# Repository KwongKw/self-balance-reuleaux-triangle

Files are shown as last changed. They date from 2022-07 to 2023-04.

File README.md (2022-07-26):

# FYP_ESP32_Self-BalanceReuleauxTriangle
It is an FYP based on the design of the self-balance Reuleaux triangle. 

To maintain the unsatble equilibrium state. the force provided by the momentum wheel need to be calculated based on the physical state of the triangle.



## Procedures

### PCB design

#### Apperance
  
- To ease the rotation of the system, the reuleaux triangle is used in the design, to minimize the force required for the system.

#### MCU

Arduino/ESP series MCUs are preferred. 
- Arduino has a well-developed library for implementing this project. 
ESP series provide wireless features including wireless programming, control, and system monitoring, and a relatively high compatibility with arduino library.

#### Sensors
- To monitor the state (angle of rotation) of the system, accelerometers are considered to be used to detect the tilt angle.

####	Motor
- To provide enough rotational force for the system, the momentum wheel is considered to be used to provide the required force

#### Charging Circuit (Optional)
- To prevent wires from affecting the mobility of the system. Power supply is better to be embedded into the system.

###	Control System
To enhance the performance for the system, different control systems will be tested on maintaining the unstable equilibrium system.

###	Calibratio
To tune the system, collect and interpret data extracted from the system, and make improvements on the system.

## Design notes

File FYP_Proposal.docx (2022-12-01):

The Hong Kong Polytechnic University

Department of Electronic and Information Engineering

Final Year Project Proposal

Self-Balance Reuleaux Triangle

Wong Keith

19067393d

Ka-Hong Loo

14-10-2022

Abstract

This project examines the self-balance Reuleaux triangle project, which can jump and balance itself on a corner (Fig. 1) [1].

A reaction wheel is embedded between two PCBs designed in the shape of a Reuleaux triangle; the reaction wheel provides a sudden force for the system to jump by braking a high-speed rotating momentum wheel suddenly; when the system reaches its unstable equilibrium state (standing with its corner), the reaction wheel is controlled to provide adjustment force for the system to prevent the system from falling.

The project aims to reproduce the design and research the performance of different control systems acting on the model.

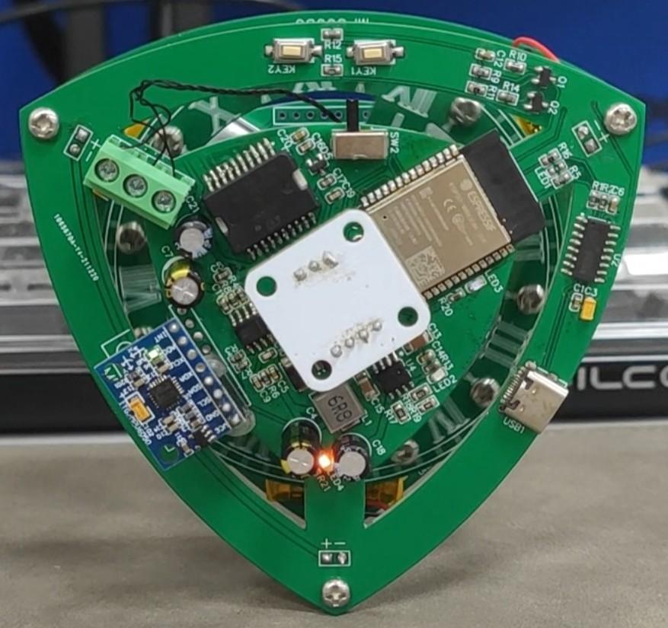
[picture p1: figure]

(Fig. 1)
Video: ﷟HYPERLINK "https://www.reddit.com/r/ElectroBOOM/comments/styhj0/selfbalanced_reuleaux_triangle/"https://www.reddit.com/r/ElectroBOOM/comments/styhj0/selfbalanced_reuleaux_triangle/ [1]

Introduction

Inverted pendulum plants are nonlinear systems widely used for testing different control algorithms [2]. The algorithm can be implemented in various fields which require stability, including vehicles (E.g., Rocket, Drone, Hoverboard, Segway), robotics (Postural controls, like walking, single leg stand) development, and even seismic control of building structures.

Reaction wheels are commonly used in the space industry; they are flywheels that can store rotational energy by rotation and trigger momentum exchange to supply rotational force for the vehicle [3][4]. Due to the high pointing accuracy provided by the wheels, the space vehicles can perform precise angle adjustments to implement exact tasks like satellite orientations and pointing the telescope at a star. Although using reaction wheels effectively reduces the need for thrusters and fuel to load onboard, the wheel can only perform rotational adjustments with respect to the center of mass.

The model concatenated both concepts mentioned above, and it is a prototype proving the use of reaction wheels on stabilizing inverted pendulum plants. There are similar projects which also demonstrate the idea, the Cubli [5], a three dimension balancing cube system on a corner.

The project will focus on implementing the product and investigating how the control systems differ in the product's

Objective

It is a project based on reproducing the product of the Self-Balance Reuleaux Triangle. The project aims to perform an unstable equilibrium with the aid of different control systems on the model.

Methodology

1. PCB Design

The contour of the PCB, which is also the main structure of the model, would be designed in the shape of the Reuleaux triangle to ease the rotation of the model. As the locus of the Reuleaux triangle is more smooth than that of ordinary triangles and squares, the sudden force needed for lifting the system can be smaller, easier the design of the reaction wheel.

The PCB design will then be sent to companies for manufacturing boards or passed to the Industrial Center for production.

  a. MCU

Computing unit for obtaining sensors' value, adjusting PWM for the motor, and the control system of the product. The following commonly used MCUs are considered.

Arduino series MCUs own a wide variety of well-developed libraries for implementing the project.

ESP series MCUs provide numerous wireless features to ease the project's development, including wireless programming, control, and system monitoring via Bluetooth and WiFi connection and relatively well-developed libraries.

STM series MCUs included a Low Layer (LL) library and hardware abstraction layer (HAL) that would have a higher degree of freedom in controlling the MCU and the hardware components. However, the ecosystem of STM lags behind the others, making the project complicated to implement.

  b. Sensors

Tilt angles need to be detected to perform the feedback control. The following are sensors to be considered.

Accelerometers are used to detect the tilt angle.

Ultrasonic sensors can also be used to help detect the distance from the corner to the ground, hence calculating the angle of rotation.

  c. Motor

To provide rotational force for the system. The motor with enough torque, which is required to be calculated after the PCB production, for driving the momentum wheel is needed.

  d. Charging Circuit (Optional)

To prevent wires from affecting the system's mobility. The power supply is better to be embedded into the system.

2. Control System

To enhance the system's performance. Different control systems (E.g., Proportional Integral Derivative (PID), Linear Quadratic Regulator (LQR) controller, and Model Predictive Control (MPC) [6]) will be tested to keep the unstable equilibrium system.

3. Calibration

To tune the system, collect and interpret data extracted from the system, and make improvements to the system.

Research Fields

1. PCB Designing

Designing a workable PCB and implementing it on a workable product.

2. MCU

System control and IOs via MCUs.

3. Control System

Research how different control systems (e.g., PID, LQR, MPC) act differently on this system, studying improvements and optimizations that can be performed on the system based on the data extracted.

Schedule

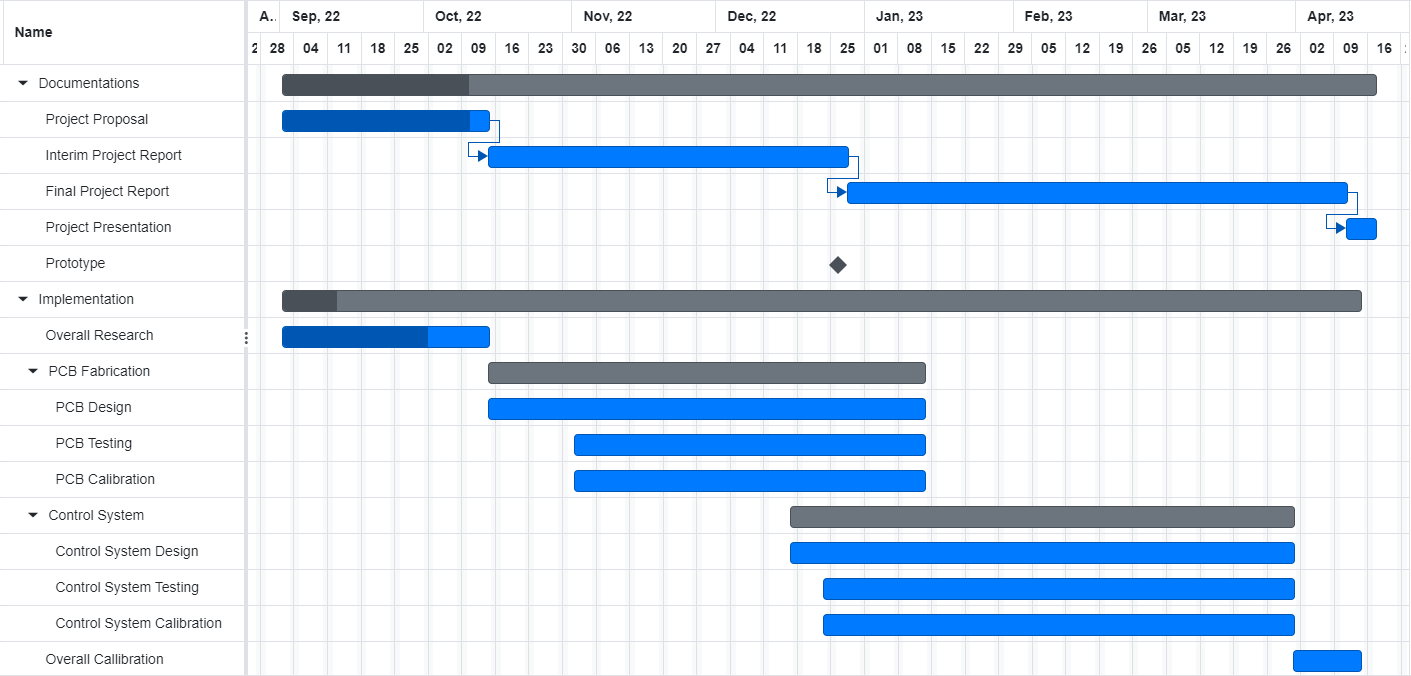
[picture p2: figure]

Reference

[1] "R/electroboom - self-balanced Reuleaux triangle!!!!!(),” Reddit. [Online]. Available: https://www.reddit.com/r/ElectroBOOM/comments/styhj0/selfbalanced_reuleaux_triangle/. [Accessed: 14-Oct-2022].

[2] E. Acurio, 'Mechanical redesign and control with a PLC of an inverted pendulum,' Congreso de Ciencia y Tecnología (ESPE), vol. 33, pp. 188, 2015.

[3] F. L. Markley, R. G. Reynolds, F. X. Liu, and K. L. Lebsock, "Maximum torque and momentum envelopes for reaction wheel arrays," Journal of Guidance, Control, and Dynamics, vol. 33, no. 5, pp. 1606–1614, 2010.

[4] M. Adetoro, COMPARATIVE DESIGN OF ATTITUDE STABILIZATION AND CONTROL SCHEMES FOR THREE AXES SPACE VEHICLE. Master Thesis on the direction "Instrumentation," 2010.

[5] M. Gajamohan, M. Merz, I. Thommen, and R. D'Andrea, "The Cubli: A cube that can jump up and balance," 2012 IEEE/RSJ International Conference on Intelligent Robots and Systems, 2012.

[6] S. Dani, D. Sonawane, D. Ingole, and S. Patil, "Performance evaluation of PID, LQR and MPC for DC Motor Speed Control," 2017 2nd International Conference for Convergence in Technology (I2CT), 2017.

Wong Keith 19067393D FYP Proposal

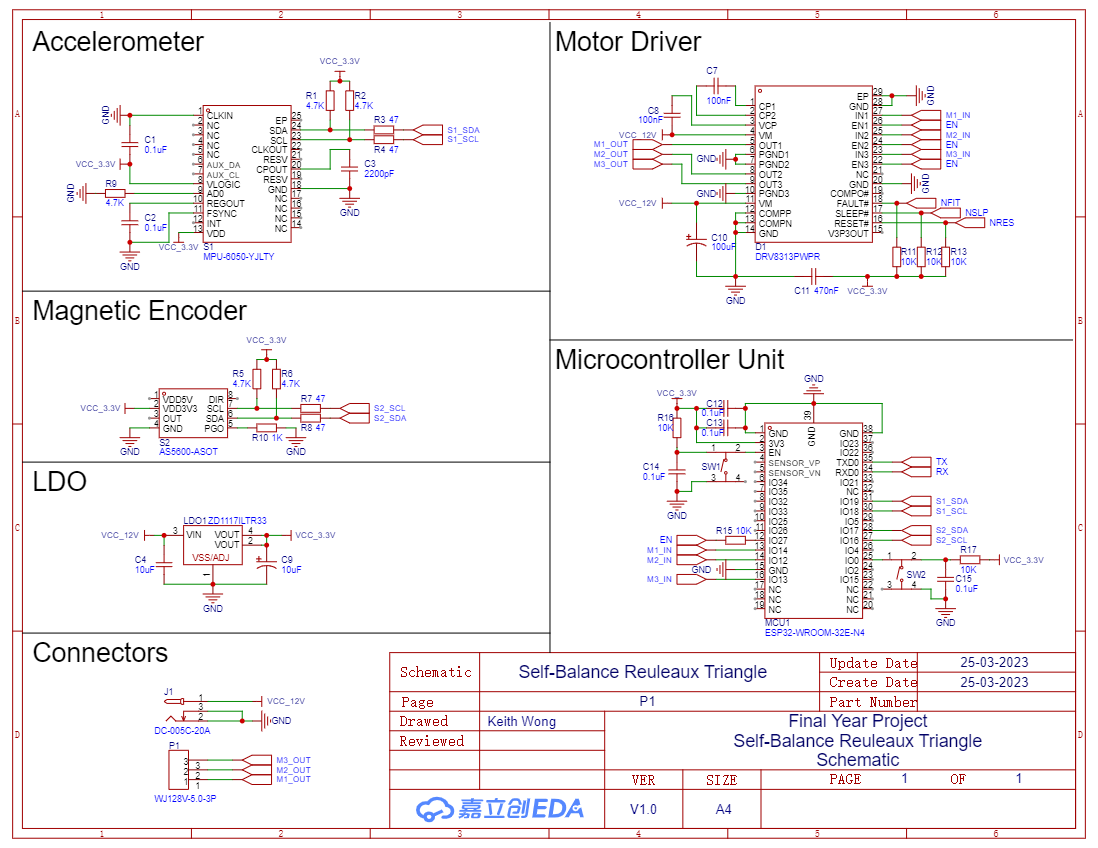
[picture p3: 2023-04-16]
hw/PCB/Schematic.png

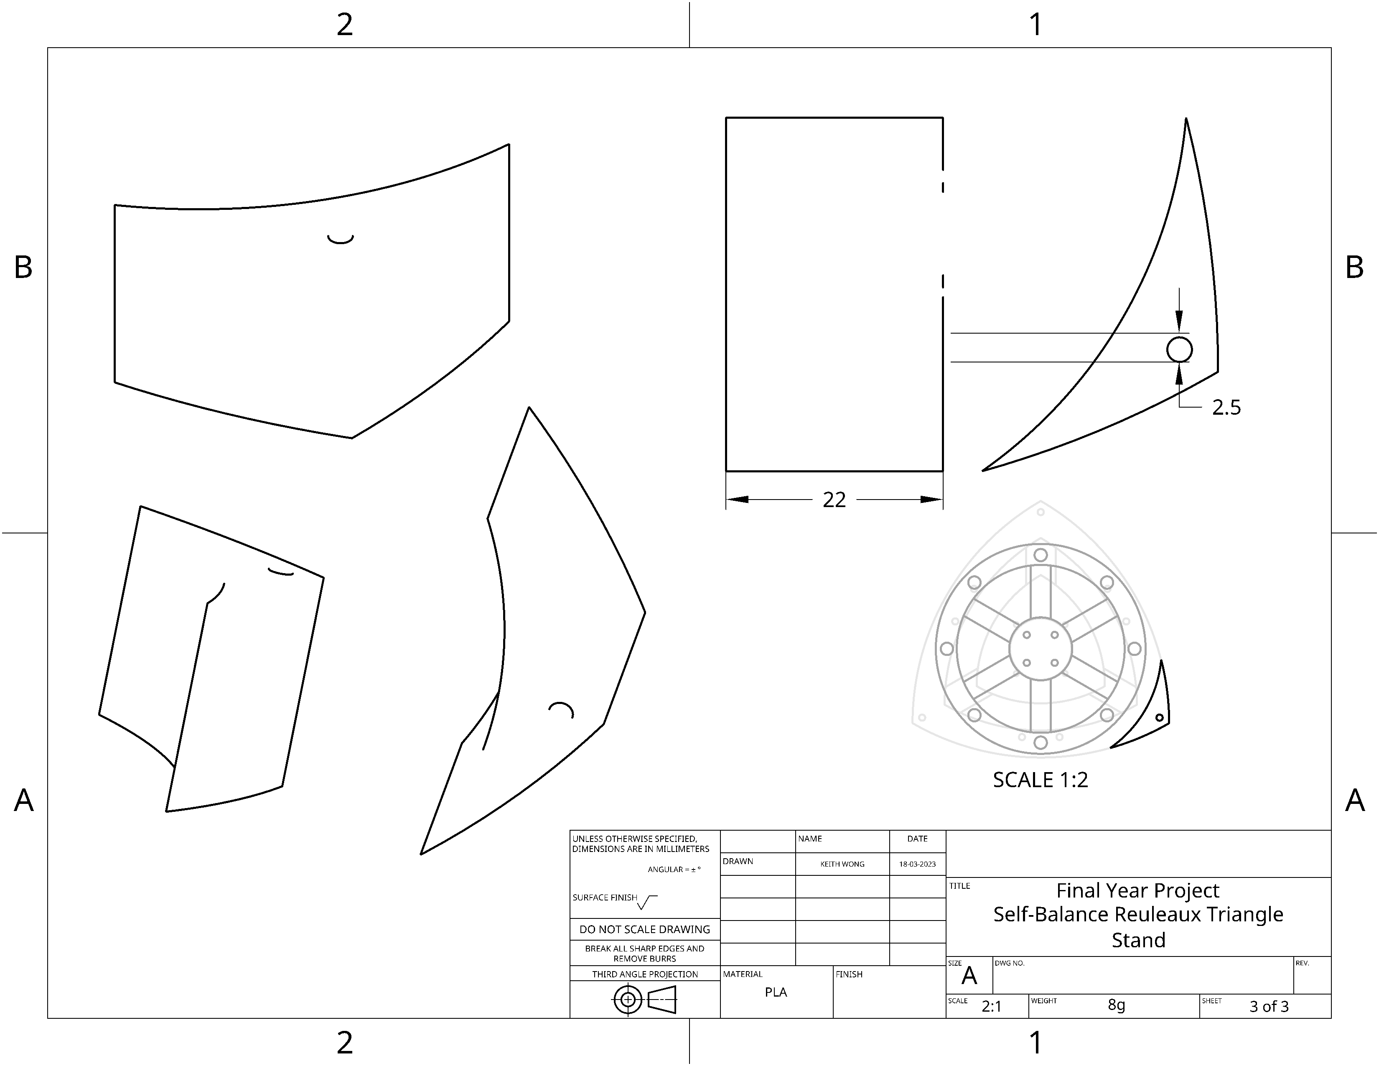
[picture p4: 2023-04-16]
hw/3D Model/Drawings/Stand.png

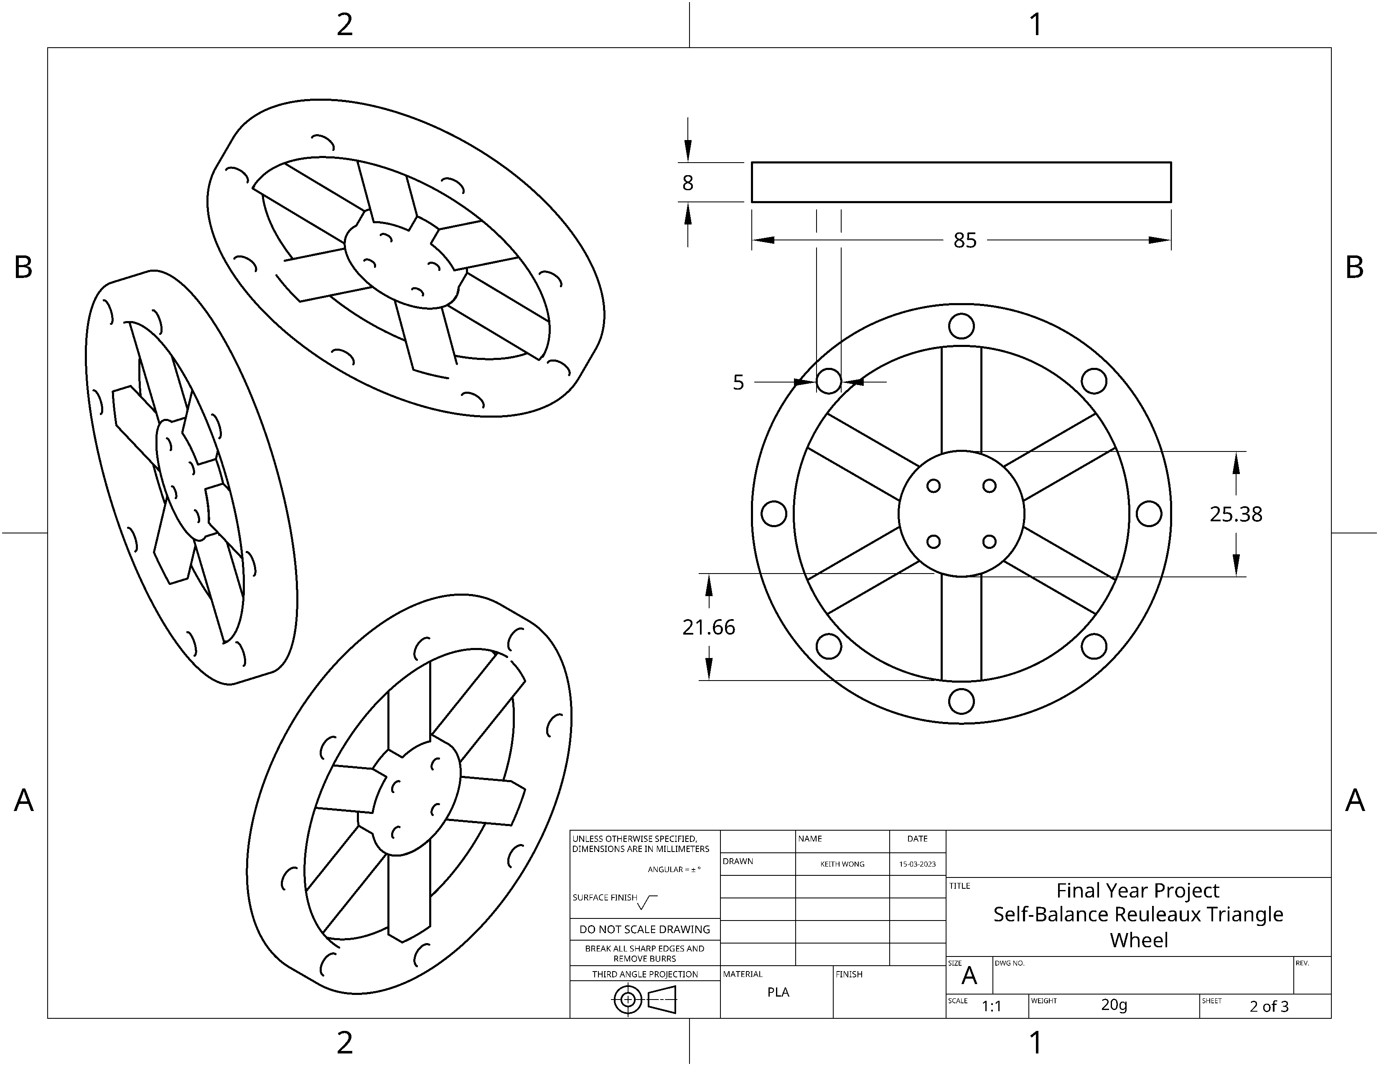
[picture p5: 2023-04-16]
hw/3D Model/Drawings/Wheel.png

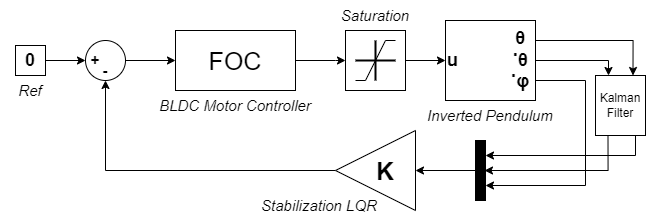
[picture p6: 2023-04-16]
hw/3D Model/Drawings/ControlSystem.png

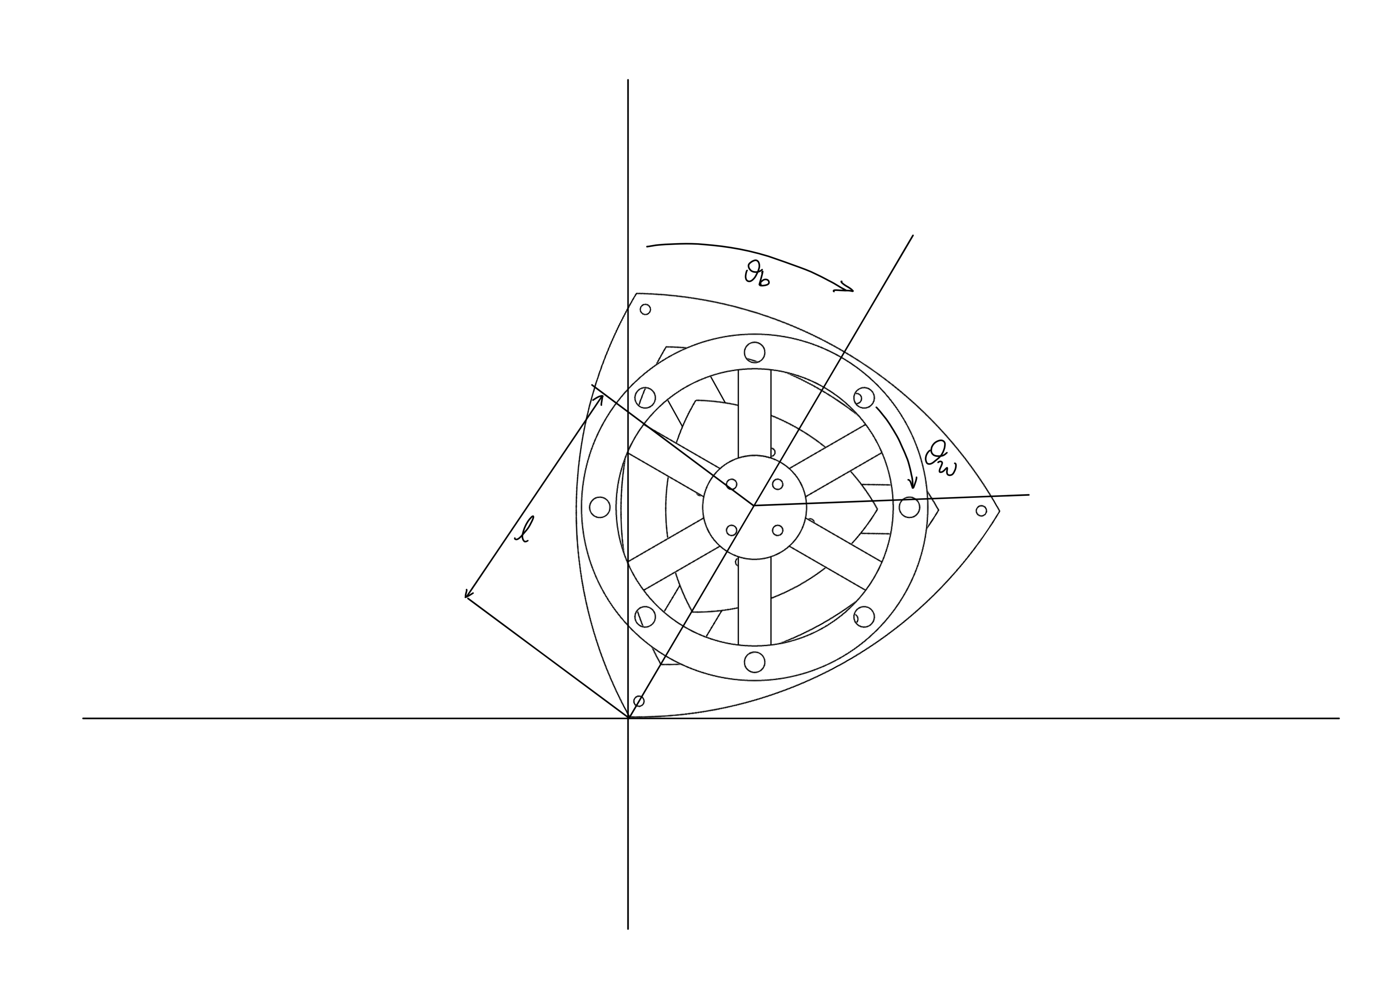
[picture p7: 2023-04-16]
hw/3D Model/Drawings/MathematicalModel.png

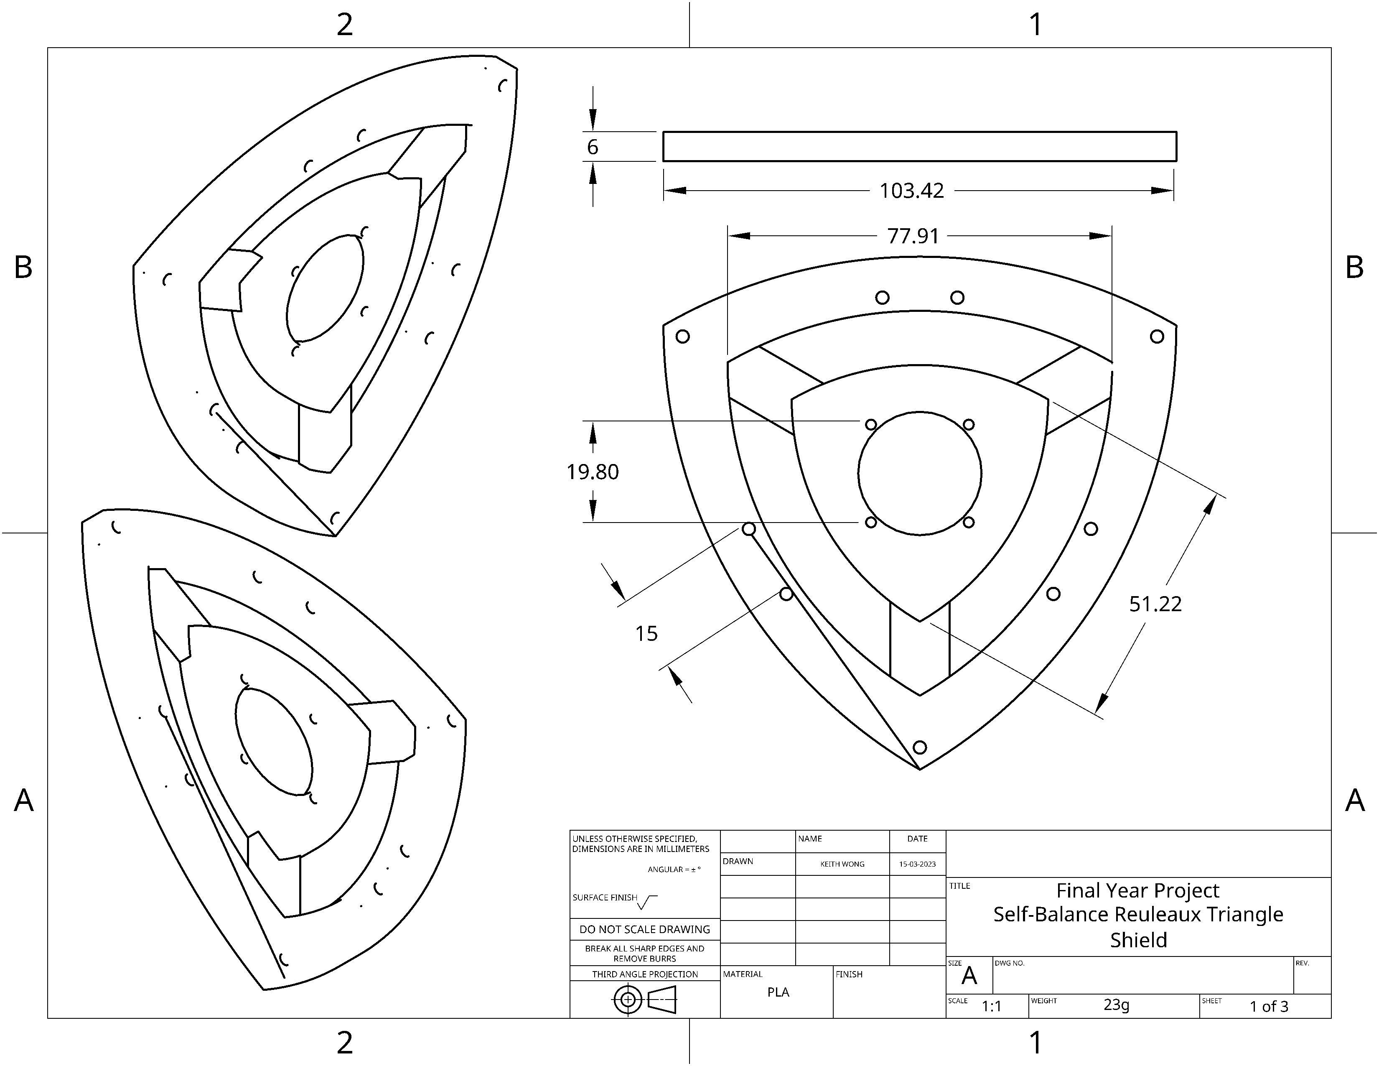
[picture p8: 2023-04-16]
hw/3D Model/Drawings/Shield.png

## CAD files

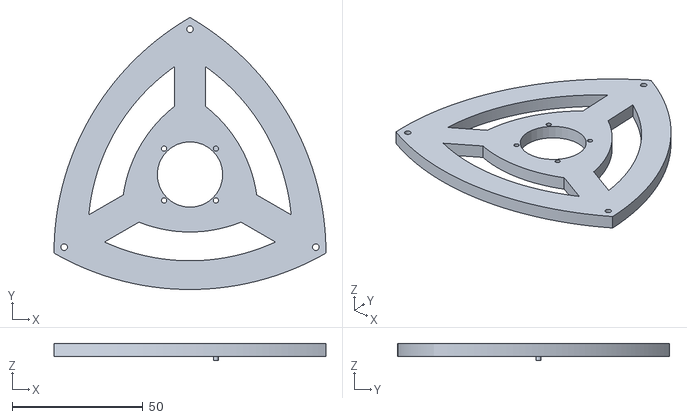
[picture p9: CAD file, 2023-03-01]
3D_Model/V2/Reuleaux.stl
103.9 x 103.9 x 6.50

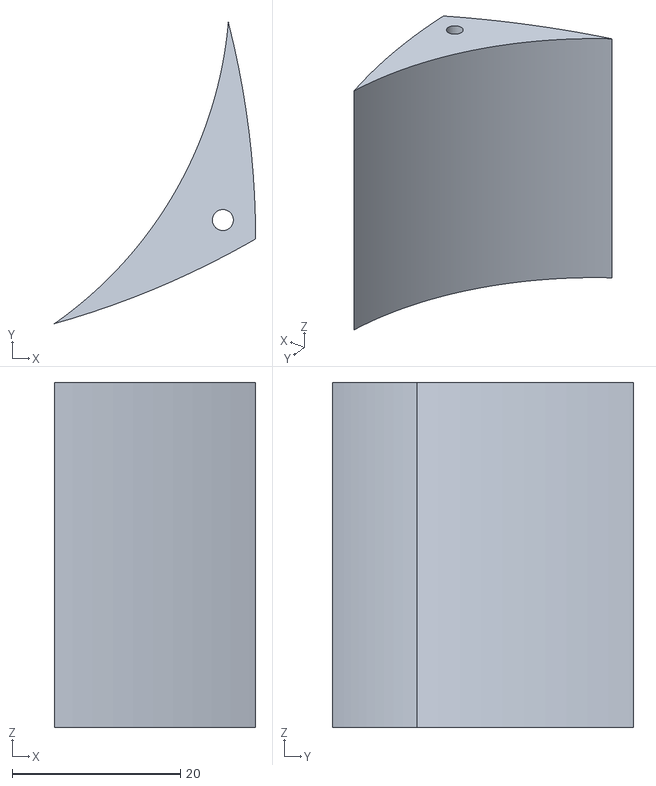
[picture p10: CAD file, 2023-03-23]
hw/3D Model/V3/Connectors.stl
23.9 x 35.8 x 41.0

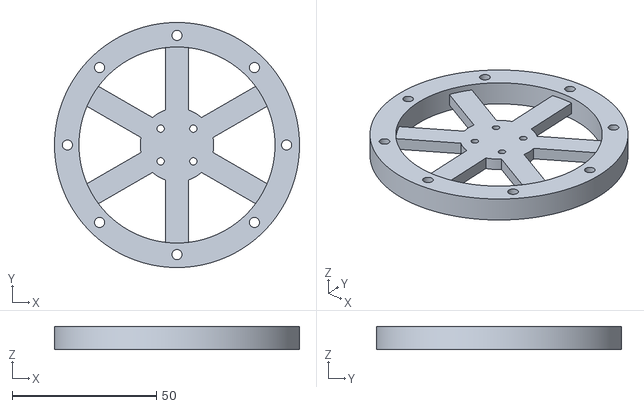
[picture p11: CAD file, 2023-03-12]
hw/3D Model/V3/Wheel.stl
85.0 x 85.0 x 8.00

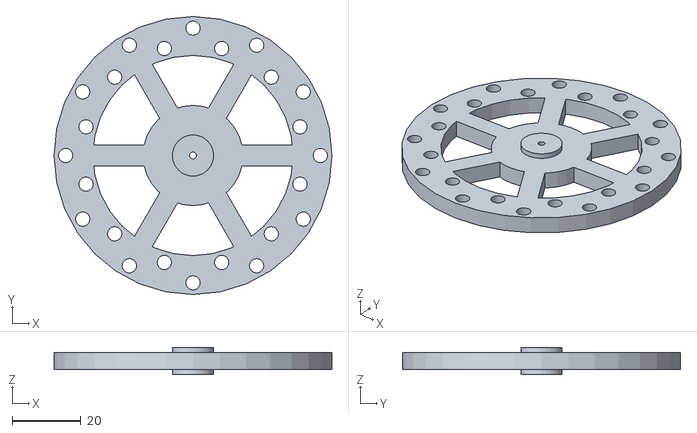
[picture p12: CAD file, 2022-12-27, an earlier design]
hw/3D Model/V1/MomentumWheel.stl
81.0 x 81.0 x 8.00

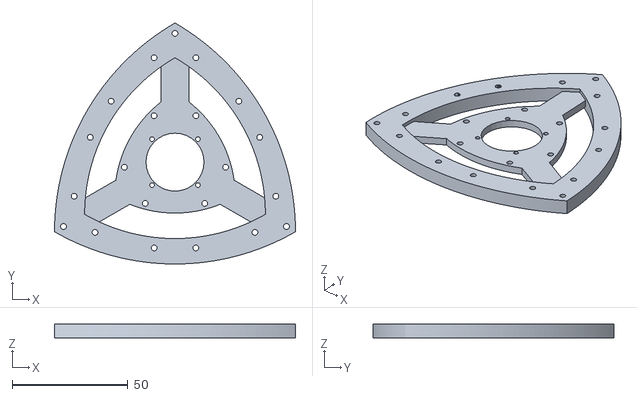
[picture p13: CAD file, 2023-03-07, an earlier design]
hw/3D Model/V2/Reuleaux.stl
103.9 x 103.9 x 6.00

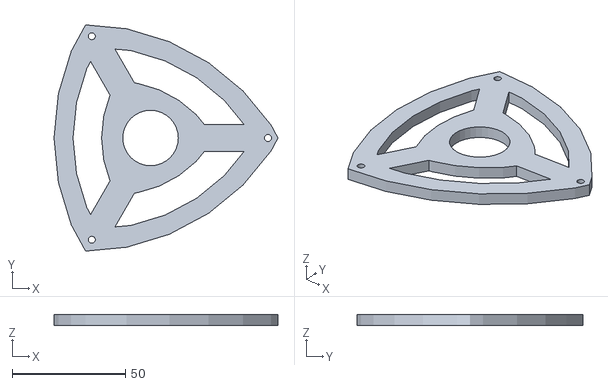
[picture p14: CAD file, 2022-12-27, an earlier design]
hw/3D Model/V1/OuterLayer.stl
98.9 x 99.9 x 4.93

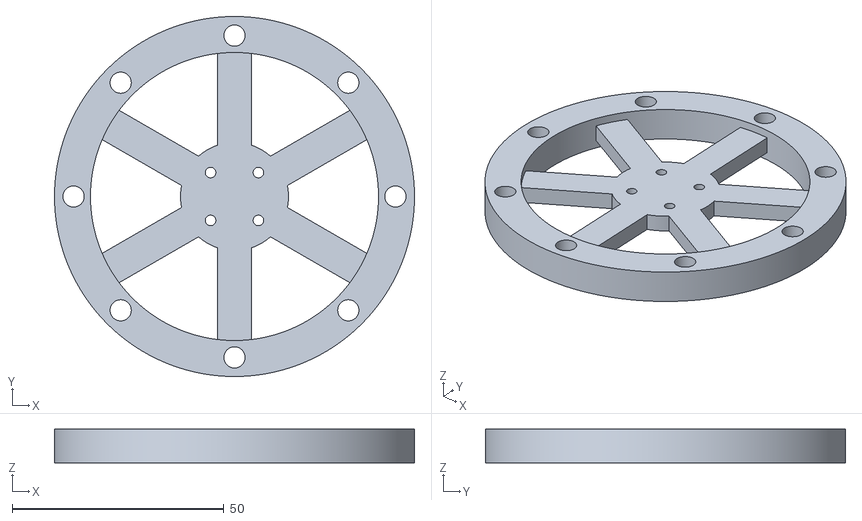
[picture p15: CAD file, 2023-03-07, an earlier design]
hw/3D Model/V2/Wheel.stl
85.0 x 85.0 x 8.00

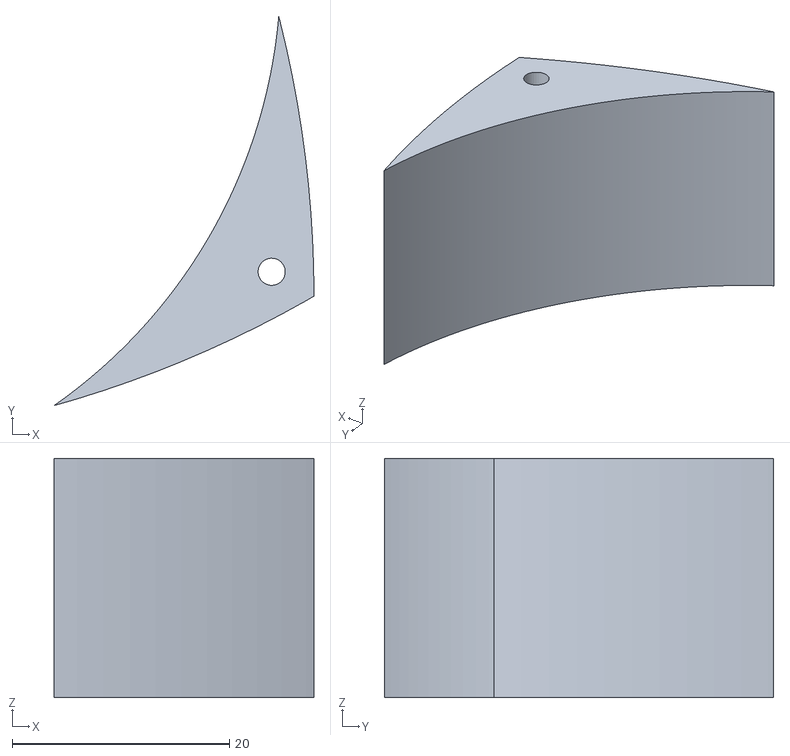
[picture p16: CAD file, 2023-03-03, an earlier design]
hw/3D Model/V2/Connectors.stl
23.9 x 35.8 x 22.0

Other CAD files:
3D_Model/V2/3D_Model.blend
hw/3D Model/V1/3D_Model.blend

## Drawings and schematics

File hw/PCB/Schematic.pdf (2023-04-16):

# Accelerometer

# Motor Driver

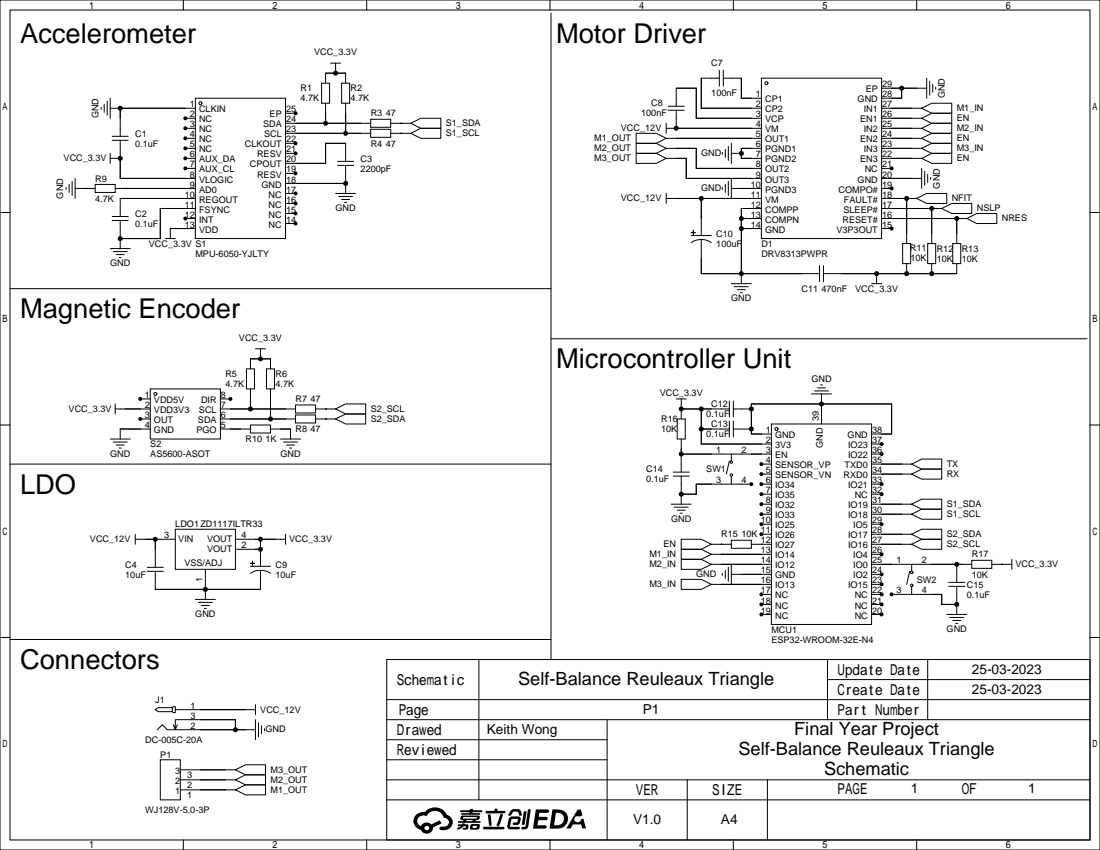
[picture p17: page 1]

Self-Balance Reuleaux Triangle

Update Date
Create Date
Part Number
Final Year Project

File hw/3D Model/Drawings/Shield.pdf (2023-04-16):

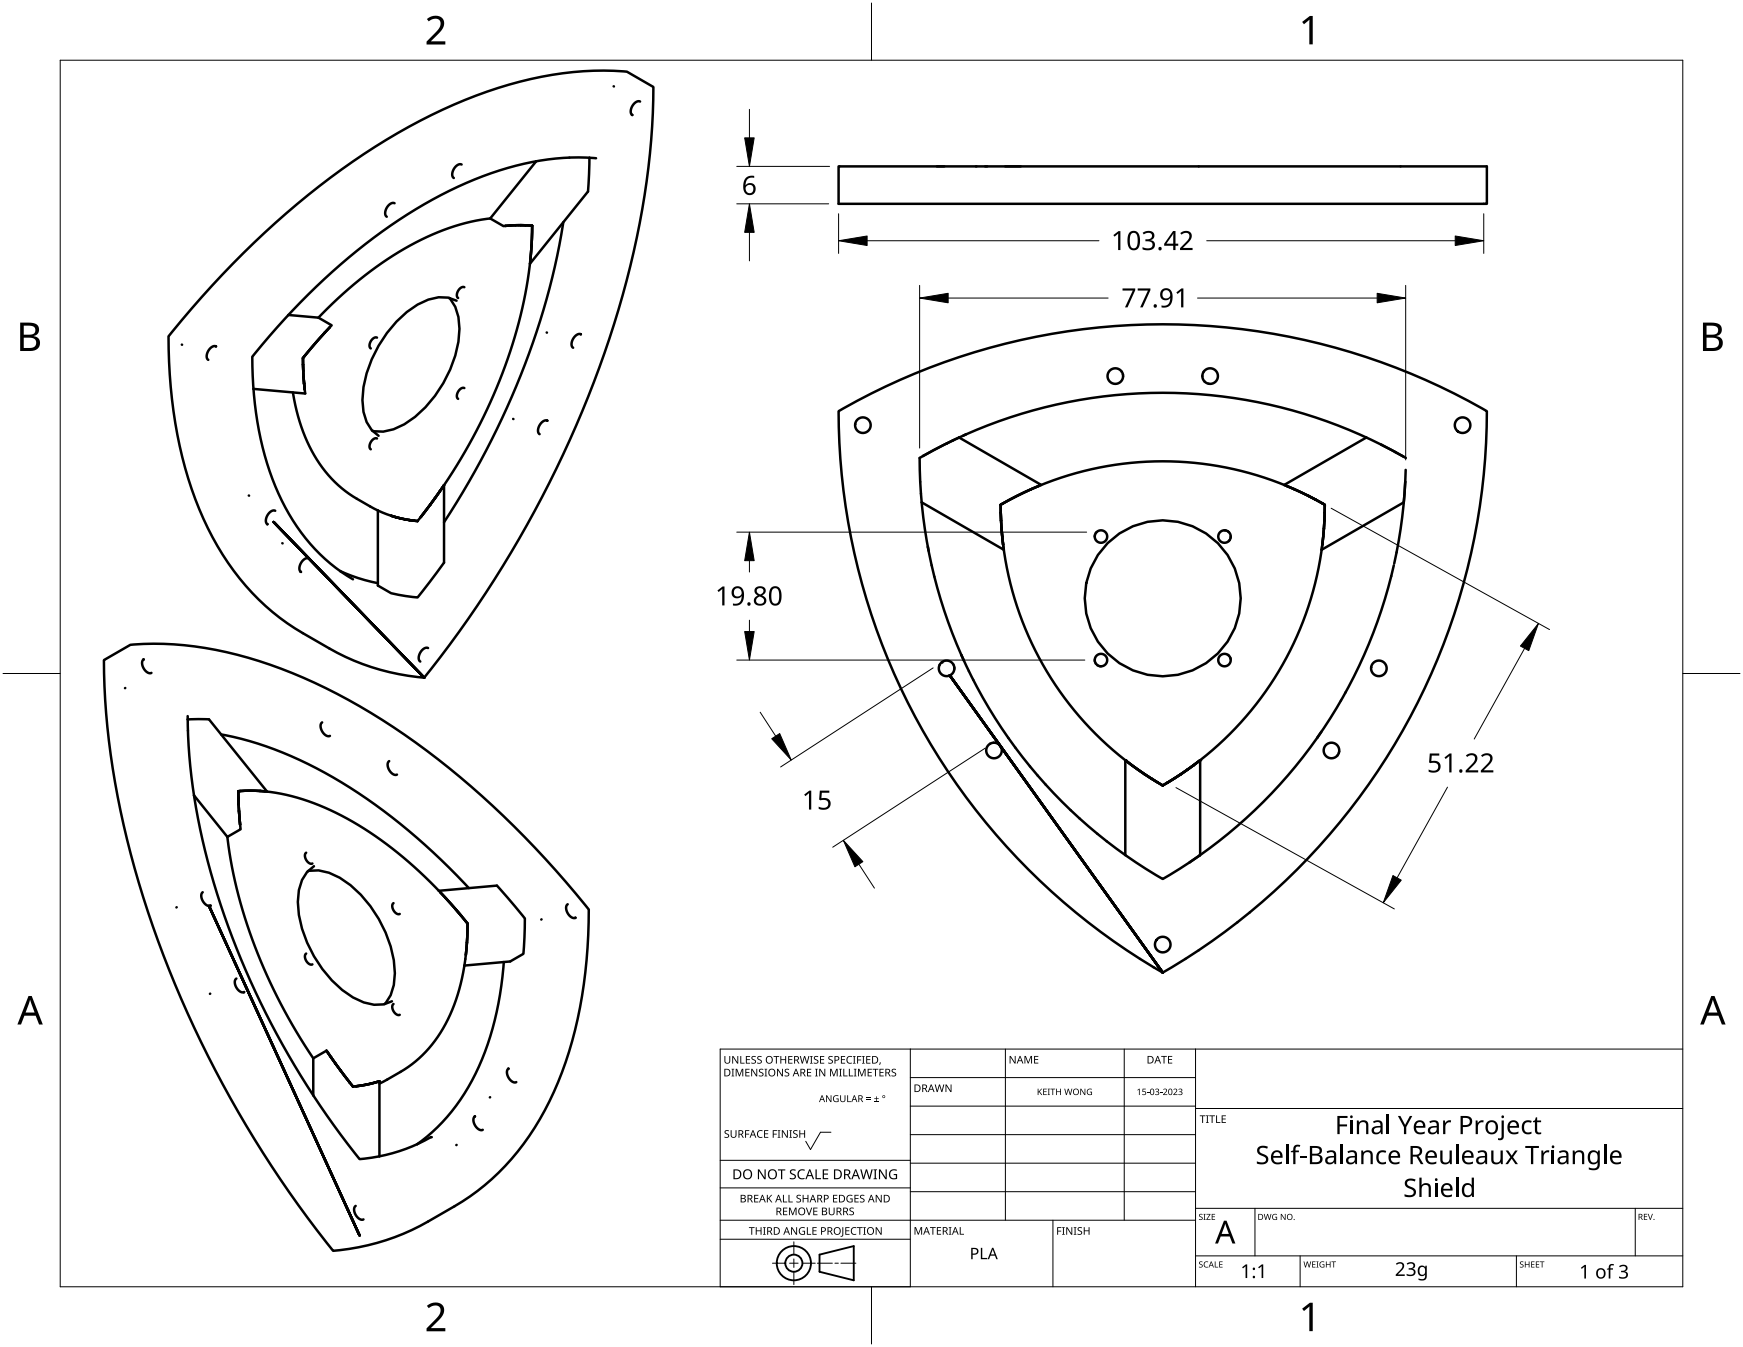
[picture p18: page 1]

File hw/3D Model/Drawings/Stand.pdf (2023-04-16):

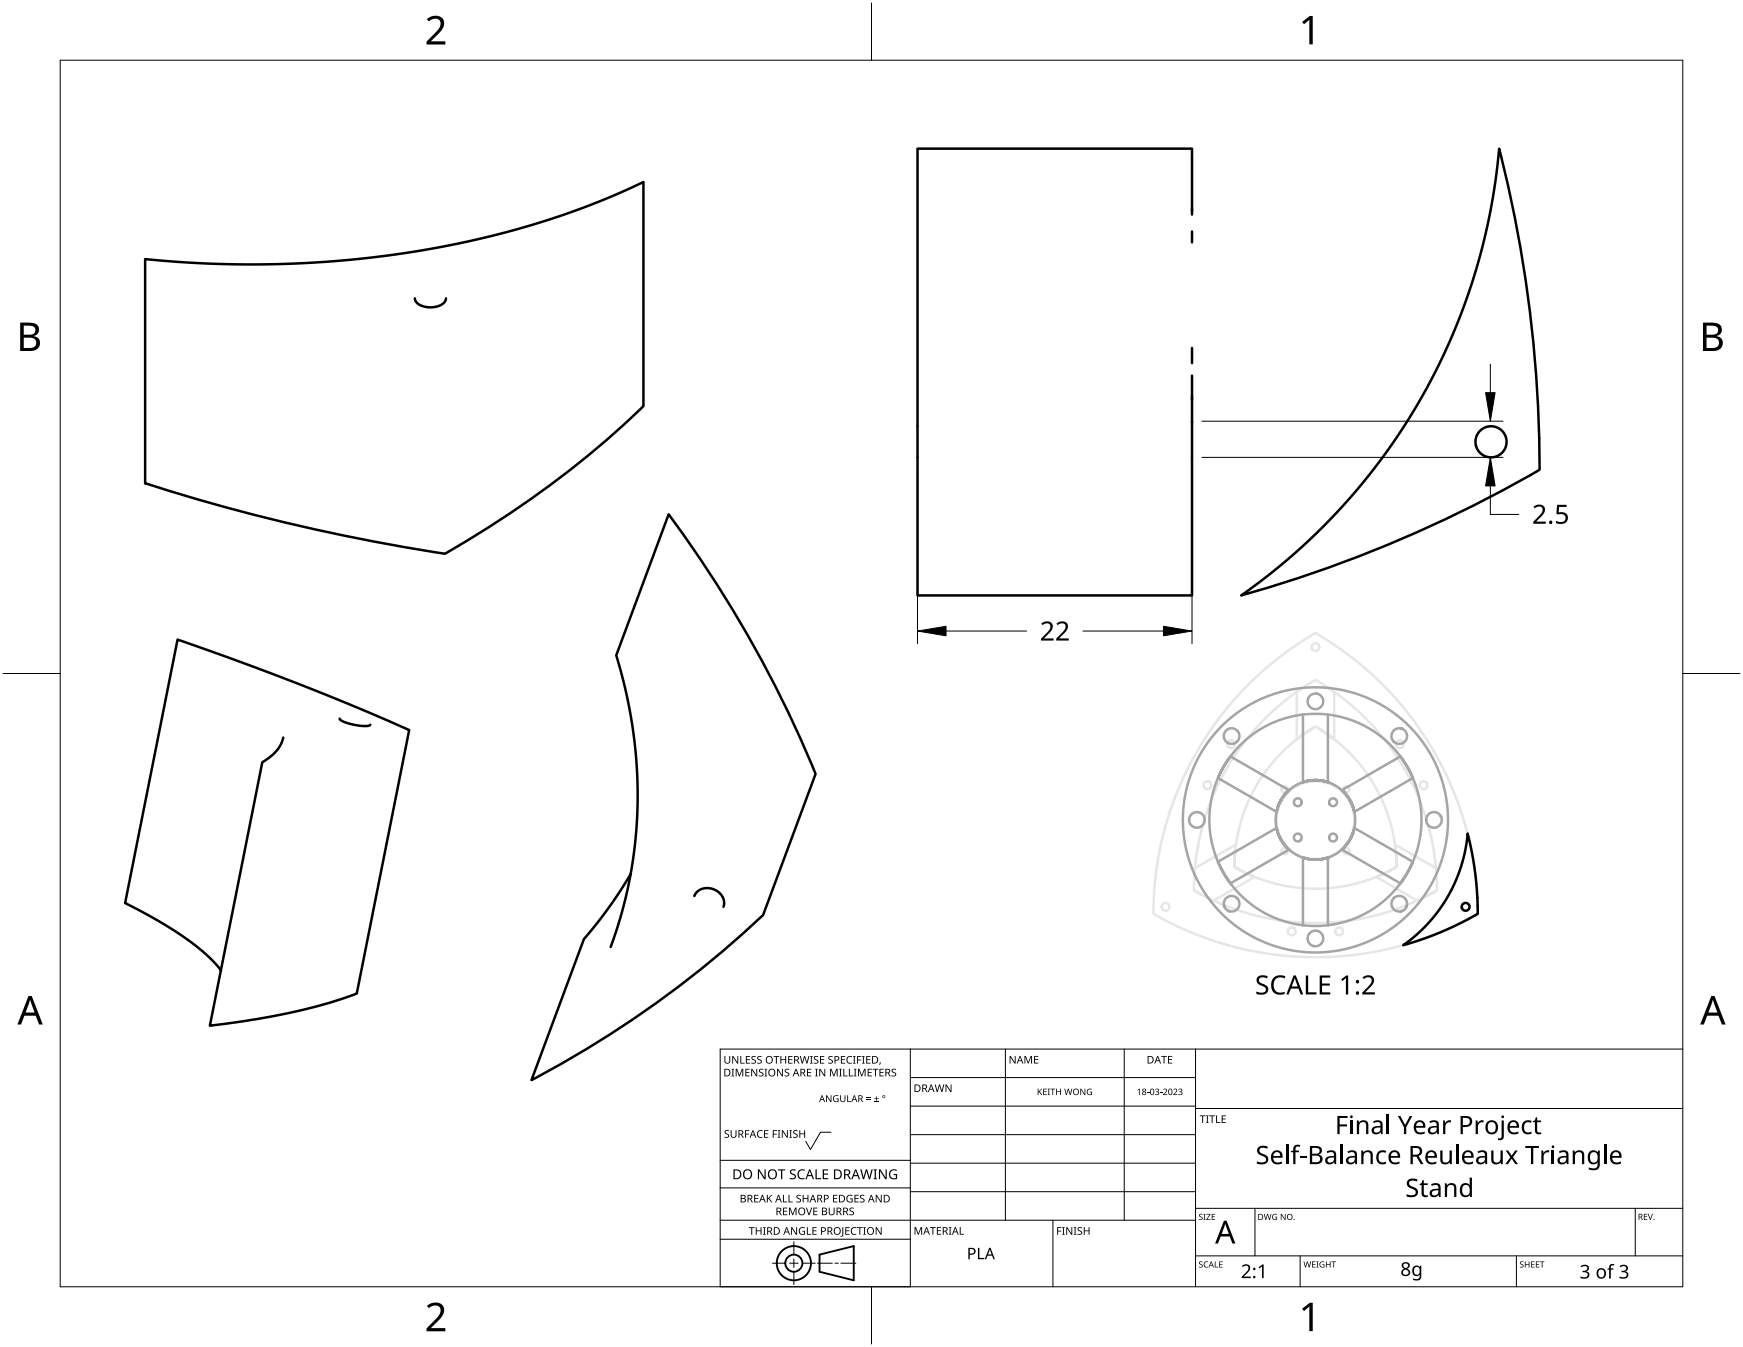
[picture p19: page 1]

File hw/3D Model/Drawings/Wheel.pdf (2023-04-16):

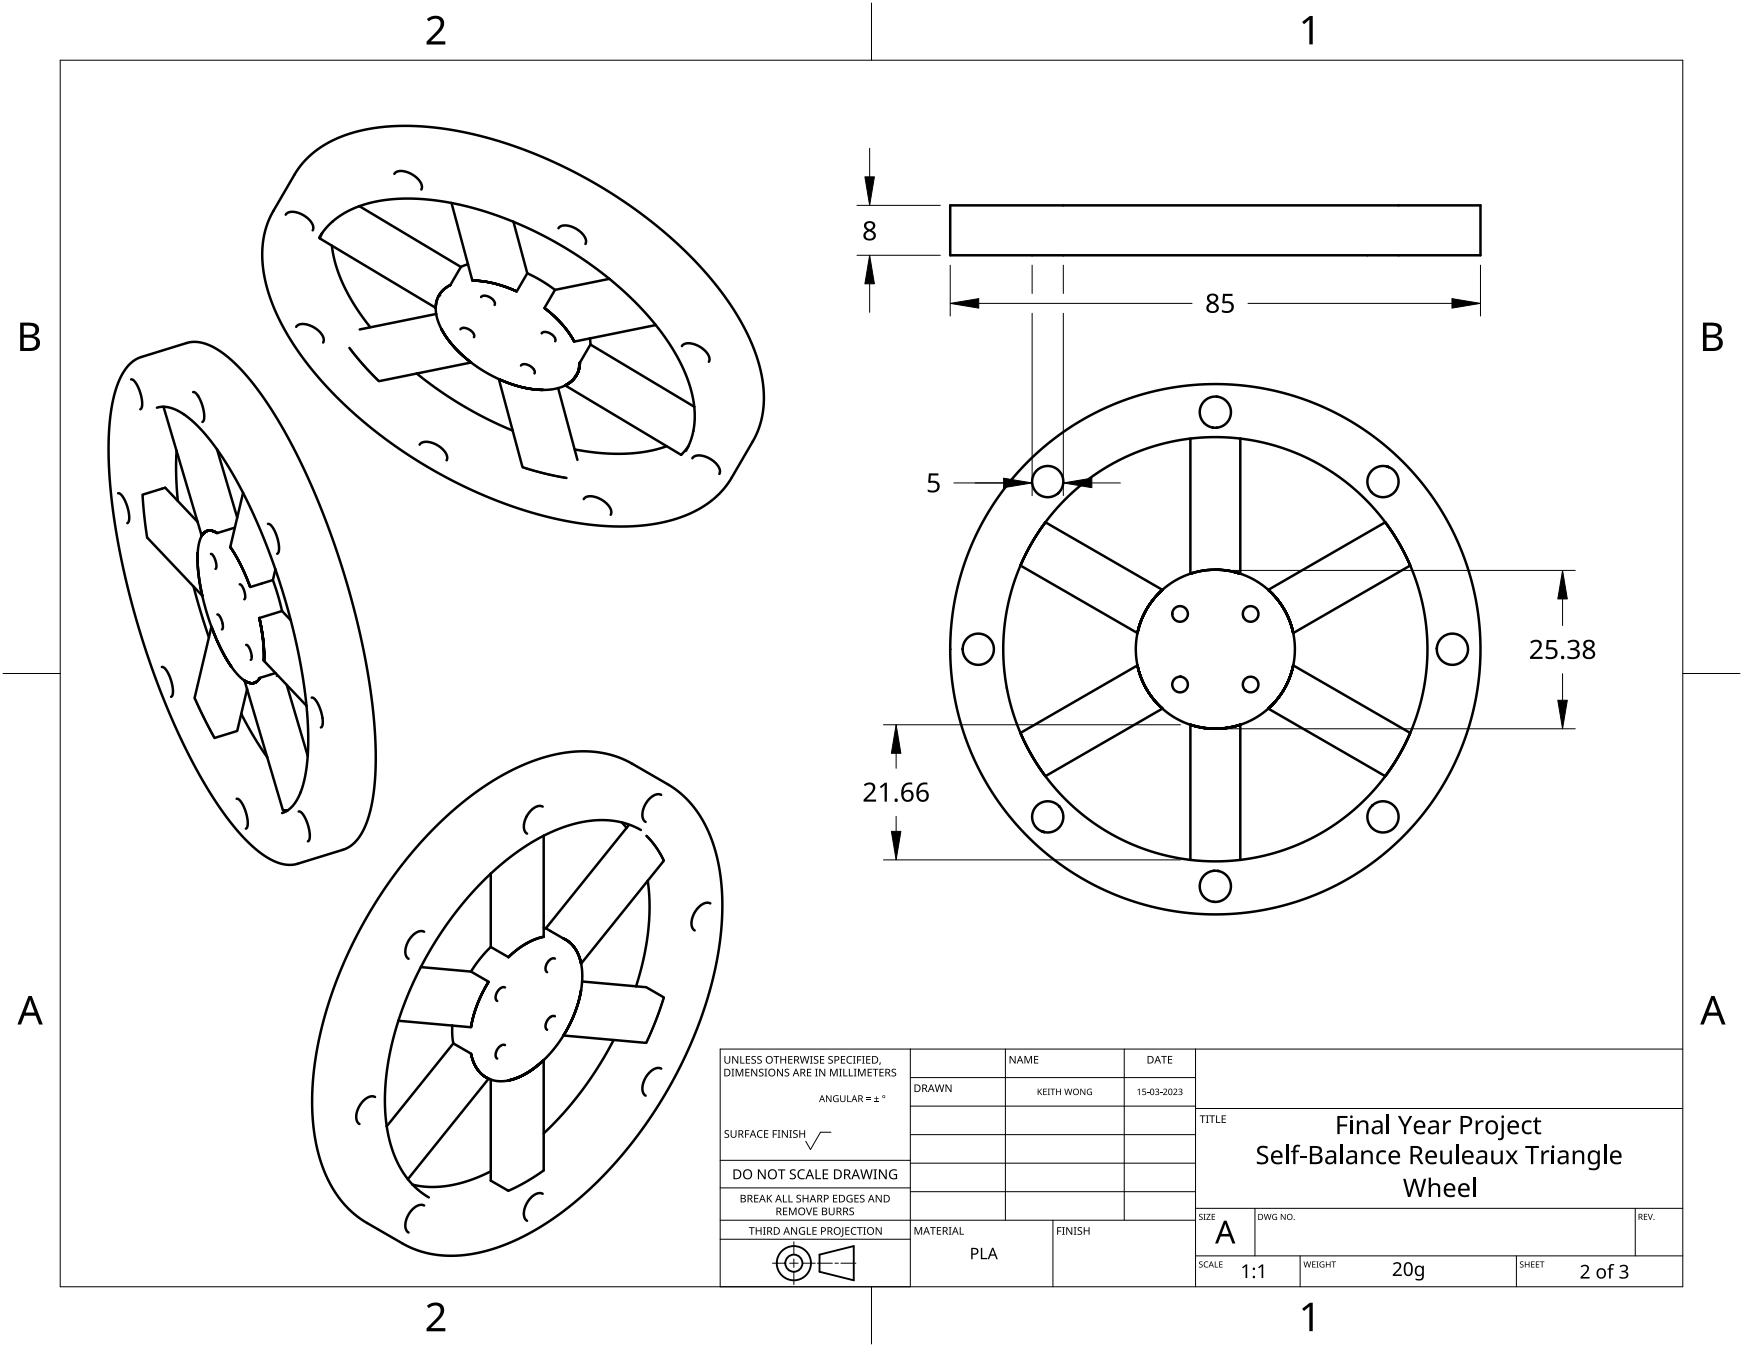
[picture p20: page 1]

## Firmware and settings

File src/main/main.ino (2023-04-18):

/**
MotorDriver 14, 12, 13, 27 (M1, M2, M3, EN)
AS5600      17, 16 (SDA, SCL)
MPU6050     19, 18 (SDA, SCL)
**/

#include <SimpleFOC.h>
#include "Kalman.h"  // Source: https://github.com/TKJElectronics/KalmanFilter
Kalman kalmanZ;
#define gyroZ_OFF -0.19
/* ----IMU Data---- */

double accX, accY, accZ;
double gyroX, gyroY, gyroZ;
int16_t tempRaw;
bool stable = 0;
uint32_t last_unstable_time;
uint32_t last_stable_time;
double gyroZangle;  // Angle calculate using the gyro only
double compAngleZ;  // Calculated angle using a complementary filter
double kalAngleZ;   // Calculated angle using a Kalman filter

uint32_t timer;
uint8_t i2cData[14];  // Buffer for I2C data
/* ----FOC Data---- */

// driver instance
double acc2rotation(double x, double y);
float constrainAngle(float x);

MagneticSensorI2C sensor = MagneticSensorI2C(AS5600_I2C);
TwoWire I2Ctwo = TwoWire(1);
LowPassFilter lpf_throttle{ 0.00 };

float LQR_K_1 = 7.1;   //70.8037
float LQR_K_2 = 1.7;   //17.1489
float LQR_K_3 = 1.75;     //1 ?

//电机参数
BLDCMotor motor = BLDCMotor(7);
BLDCDriver3PWM driver = BLDCDriver3PWM(14, 12, 13, 27);

float target_velocity = 0;
float target_angle = 89.3;
float target_voltage = 0;
float swing_up_voltage = 1;
float swing_up_angle = 15;

float v_p = 0.2;   //0.05      //P
float v_i = 0.4;   //0.5      //I
float v_d = 0.0;  //0.01     //D
//---------------------------------------------------------------------------------------------------------------------//
void setup() {
  Serial.begin(115200);

  // kalman mpu6050 init
  Wire.begin(19, 18, 400000);  // Set I2C frequency to 400kHz
  i2cData[0] = 7;              // Set the sample rate to 1000Hz - 8kHz/(7+1) = 1000Hz
  i2cData[1] = 0x00;           // Disable FSYNC and set 260 Hz Acc filtering, 256 Hz Gyro filtering, 8 KHz sampling
  i2cData[2] = 0x00;           // Set Gyro Full Scale Range to ±250deg/s
  i2cData[3] = 0x00;           // Set Accelerometer Full Scale Range to ±2g
  while (i2cWrite(0x19, i2cData, 4, false));  // Write to all four registers at once
  while (i2cWrite(0x6B, 0x01, true));  // PLL with X axis gyroscope reference and disable sleep mode
  while (i2cRead(0x75, i2cData, 1));
  if (i2cData[0] != 0x68) {  // Read "WHO_AM_I" register
    Serial.print(F("Error reading sensor"));
    while (1);
  }
  delay(100);  // Wait for sensor to stabilize

  /* Set kalman and gyro starting angle */
  while (i2cRead(0x3B, i2cData, 6))
    ;
  accX = (int16_t)((i2cData[0] << 8) | i2cData[1]);
  accY = (int16_t)((i2cData[2] << 8) | i2cData[3]);
  accZ = (int16_t)((i2cData[4] << 8) | i2cData[5]);
  double pitch = acc2rotation(accX, accY);
  kalmanZ.setAngle(pitch);
  gyroZangle = pitch;
  timer = micros();
  Serial.println("kalman mpu6050 init");

  // AS5600 init
  I2Ctwo.begin(17, 16, 400000);  //SDA,SCL
  sensor.init(&I2Ctwo);
  motor.linkSensor(&sensor);

  // FOCDriver init
  driver.voltage_power_supply = 12;
  driver.init();
  motor.linkDriver(&driver);

  // pwm modulation settings
  motor.foc_modulation = FOCModulationType::SpaceVectorPWM;

  // control loop type and torque mode
  motor.controller = MotionControlType::velocity;

  // velocity loop PID
  motor.PID_velocity.P = v_p;
  motor.PID_velocity.I = v_i;
  motor.PID_velocity.D = v_d;
  motor.PID_velocity.limit = 40;
  // Low pass filtering time constant
  motor.LPF_velocity.Tf = 0.01;

  // Limits
  motor.voltage_limit = 12;
  motor.voltage_sensor_align = 2;
  motor.current_limit = 1.5;

  //motor.useMonitoring(Serial);

  // initialize motor
  motor.init();
  // align sensor and start FOC
  motor.initFOC();

  Serial.println("Success");
}

double last_pitch;
//-----------------------------------------------------------------------------------------------------------------------------//
void loop() {
  motor.loopFOC();

  while (i2cRead(0x3B, i2cData, 14))
    ;
  accX = (int16_t)((i2cData[0] << 8) | i2cData[1]);
  accY = (int16_t)((i2cData[2] << 8) | i2cData[3]);
  accZ = (int16_t)((i2cData[4] << 8) | i2cData[5]);
  tempRaw = (int16_t)((i2cData[6] << 8) | i2cData[7]);
  gyroX = (int16_t)((i2cData[8] << 8) | i2cData[9]);
  gyroY = (int16_t)((i2cData[10] << 8) | i2cData[11]);
  gyroZ = (int16_t)((i2cData[12] << 8) | i2cData[13]);

  double dt = (double)(micros() - timer) / 1000000;  // Calculate delta time
  timer = micros();

  double pitch = acc2rotation(accX, accY);

  double gyroZrate = gyroZ / 131.0;  // Convert to deg/s
  if (abs(pitch - last_pitch) > 100)
    kalmanZ.setAngle(pitch);

  kalAngleZ = kalmanZ.getAngle(pitch, gyroZrate + gyroZ_OFF, dt);
  last_pitch = pitch;
  gyroZangle += (gyroZrate + gyroZ_OFF) * dt;
  compAngleZ = 0.93 * (compAngleZ + (gyroZrate + gyroZ_OFF) * dt) + 0.07 * pitch;

  // Reset the gyro angle when it has drifted too much
  if (gyroZangle < -180 || gyroZangle > 180)
    gyroZangle = kalAngleZ;

  float pendulum_angle = constrainAngle(fmod(kalAngleZ, 120) - target_angle);

  //   pendulum_angle = error
  if (abs(pendulum_angle) < swing_up_angle)  // if angle small enough stabilize
  {
    target_velocity = controllerLQR(pendulum_angle, gyroZrate, motor.shaft_velocity);
    if (abs(target_velocity) > 140)
      target_velocity = _sign(target_velocity) * 140;
    motor.controller = MotionControlType::velocity;
    motor.move(target_velocity);
  } else  // else do swing-up
  {       // sets swing_up_voltage to the motor in order to swing up
    motor.controller = MotionControlType::torque;
    //target_voltage = -_sign(gyroZrate) * swing_up_voltage;
    target_voltage = 0;
    motor.move(target_voltage);
  }

//Debug
#if 0
    Serial.print(target_velocity);Serial.print("\t");
    Serial.print(pitch);Serial.print("\t");
    Serial.print(kalAngleZ);Serial.print("\t");
    Serial.print(target_voltage);Serial.print("\t");
    Serial.print(motor.shaft_velocity);Serial.print("\t");
    Serial.print(motor.voltage.q);Serial.print("\t");
    Serial.print(target_angle);Serial.print("\t");
    Serial.print(pendulum_angle);Serial.print("\t");
    Serial.print(gyroZrate);Serial.print("\r\n");
#endif
}

double acc2rotation(double x, double y) {
  double tmp_kalAngleZ = atan(x / y) * 180.0 / PI;
  if (y < 0) {
    return (tmp_kalAngleZ + 180);
  } else if (x < 0) {
    return (tmp_kalAngleZ + 360);
  } else return tmp_kalAngleZ;
}

// function constraining the angle in between -60~60
float constrainAngle(float x) {
  float a = 0;
  if (x < 0) {
    a = 120 + x;
    if (a < abs(x))
      return a;
  }
  return x;
}

// TODO
// PID stabilization controller functions
// calculating the voltage that needs to be set to the motor in order to stabilize the pendulum
float controllerPID(float p_angle){}

// LQR stabilization controller functions
// calculating the voltage that needs to be set to the motor in order to stabilize the pendulum
float controllerLQR(float p_angle, float p_vel, float m_vel) {
  if (abs(p_angle) > 5) {
    last_unstable_time = millis();
    stable = 0;
  }
  if ((millis() - last_unstable_time) > 1000 && !stable) {
    target_angle = target_angle + p_angle;
    stable = 1;
  }
  if ((millis() - last_stable_time) > 2500 && stable) {
    if (abs(target_velocity) > 5) {
      last_stable_time = millis();
      target_angle -= _sign(target_velocity) * 0.2;
    }
  }

  float u = LQR_K_1 * p_angle + LQR_K_2 * p_vel + LQR_K_3 * m_vel;
  return u;
}

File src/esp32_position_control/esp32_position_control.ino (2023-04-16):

/**
 * ESP32 position motion control example with magnetic sensor
 */
#include <SimpleFOC.h>

// SPI Magnetic sensor instance (AS5047U example)
// MISO 12
// MOSI 9
// SCK 14
// magnetic sensor instance - SPI
// MagneticSensorSPI sensor = MagneticSensorSPI(AS5147_SPI, 15);

// I2C Magnetic sensor instance (AS5600 example)
// make sure to use the pull-ups!!
// SDA 21
// SCL 22
// magnetic sensor instance - I2C
MagneticSensorI2C sensor = MagneticSensorI2C(AS5600_I2C);
TwoWire I2Ctwo = TwoWire(1);
//TwoWire I2Ctwo = TwoWire(1);
// Analog output Magnetic sensor instance (AS5600)
// MagneticSensorAnalog sensor = MagneticSensorAnalog(A1, 14, 1020);

// Motor instance
BLDCMotor motor = BLDCMotor(7);
BLDCDriver3PWM driver = BLDCDriver3PWM(14, 12, 13, 27);


// angle set point variable
float target_velocity = 0;
// instantiate the commander
Commander command = Commander(Serial);
void doTarget(char* cmd) {
  command.scalar(&target_velocity, cmd);
}
void doMotor(char* cmd) {
  command.motor(&motor, cmd);
}

void setup() {

  // initialise magnetic sensor hardware
  // link the motor to the sensor
  I2Ctwo.begin(17, 16, 400000);  //SDA,SCL
  sensor.init(&I2Ctwo);
  motor.linkSensor(&sensor);
  
  // control loop type and torque mode
  motor.torque_controller = TorqueControlType::voltage;
  motor.controller = MotionControlType::angle;
  motor.motion_downsample = 0;

  // velocity loop PID
  motor.PID_velocity.P = 0;
  motor.PID_velocity.I = 0;
  motor.PID_velocity.D = 0;
  motor.PID_velocity.output_ramp = 0;
  motor.PID_velocity.limit = 0;
  // Low pass filtering time constant
  motor.LPF_velocity.Tf = 0;
  // angle loop PID
  motor.P_angle.P = 0;
  motor.P_angle.I = 0;
  motor.P_angle.D = 0;
  motor.P_angle.output_ramp = 0;
  motor.P_angle.limit = 0;
  // Low pass filtering time constant
  motor.LPF_angle.Tf = 0;
  // current q loop PID
  motor.PID_current_q.P = 0;
  motor.PID_current_q.I = 0;
  motor.PID_current_q.D = 0;
  motor.PID_current_q.output_ramp = 0;
  motor.PID_current_q.limit = 0;
  // Low pass filtering time constant
  motor.LPF_current_q.Tf = 0;
  // current d loop PID
  motor.PID_current_d.P = 0;
  motor.PID_current_d.I = 0;
  motor.PID_current_d.D = 0;
  motor.PID_current_d.output_ramp = 0;
  motor.PID_current_d.limit = 0;
  // Low pass filtering time constant
  motor.LPF_current_d.Tf = 0;
  // Limits
  motor.velocity_limit = 0;
  motor.voltage_limit = 0;
  motor.current_limit = 0;
  // sensor zero offset - home position
  motor.sensor_offset = 0;
  // general settings
  // motor phase resistance
  motor.phase_resistance = 0;
  // pwm modulation settings
  motor.foc_modulation = FOCModulationType::SinePWM;
  motor.modulation_centered = 1;

  // driver config
  /**
  // power supply voltage [V]
  driver.voltage_power_supply = 12;
  driver.init();
  // link the motor and the driver
  motor.linkDriver(&driver);

  // choose FOC modulation (optional)
  motor.foc_modulation = FOCModulationType::SpaceVectorPWM;

  // set motion control loop to be used
  motor.controller = MotionControlType::velocity;

  // contoller configuration
  // default parameters in defaults.h

  // velocity PI controller parameters
  motor.PID_velocity.P = 0.5;
  motor.PID_velocity.I = 0.05;
  // maximal voltage to be set to the motor
  //最大电机限制电机
  motor.voltage_limit = 12;
  motor.voltage_sensor_align = 2;
  motor.current_limit = 1.5;

  //速度低通滤波时间常数
  motor.LPF_velocity.Tf = 0.01;

  //设置最大速度限制
  motor.velocity_limit = 40;
  **/
  // use monitoring with serial
  Serial.begin(115200);
  // comment out if not needed
  motor.useMonitoring(Serial);


  // initialize motor
  motor.init();
  // align sensor and start FOC
  motor.initFOC();

  // add target command T
  command.add('T', doTarget, "target velocity");
  command.add('M', doMotor, "motor");

  Serial.println(F("Motor ready."));
  Serial.println(F("Set the target velocity using serial terminal:"));
  _delay(1000);
}

void loop() {

  // main FOC algorithm function
  // the faster you run this function the better
  // Arduino UNO loop  ~1kHz
  // Bluepill loop ~10kHz
  motor.loopFOC();

  // Motion control function
  // velocity, position or voltage (defined in motor.controller)
  // this function can be run at much lower frequency than loopFOC() function
  // You can also use motor.move() and set the motor.target in the code
  motor.move(target_velocity);


  // function intended to be used with serial plotter to monitor motor variables
  // significantly slowing the execution down!!!!
  motor.monitor();

  // user communication
  command.run();
}

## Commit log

2022-12-01 Add 3d model
    [3D_Model.blend]
2022-12-27 update 3d models
    [3D_Model.blend, MomentumWheel.stl, OuterLayer.stl]
2023-02-27 add 3dmodel
    [3D_Model.blend, MomentumWheel.stl, OuterLayer.stl]
2023-02-28 modified 3D model
    [3D_Model.blend]
2023-03-01 added reuleaux stl
    [3D_Model.blend, Reuleaux.stl]
2023-03-02 modified 3D model, added wheel
    [3D_Model.blend]
2023-03-02 added wheel gcode
2023-03-03 added connectors
    [Connectors.stl]
2023-03-07 update connectors
2023-03-07 refactor tree
    [3D_Model.blend, Connectors.stl, MomentumWheel.stl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]
2023-03-07 update reuleaux
    [Reuleaux.stl]
2023-03-12 update hw V3
    [Reuleaux.stl, Wheel.stl]
2023-03-13 revert 3D model
    [Connectors.stl, Reuleaux.stl]
2023-03-23 update 3D model
    [Connectors.stl]
2023-04-16 stl fix
